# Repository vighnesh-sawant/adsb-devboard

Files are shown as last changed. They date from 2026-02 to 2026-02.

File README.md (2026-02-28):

# adsb-devboard
A devboard with an fpga  and an ADS-B reciever

# Why
When I was younger, I always wanted to tinker with radio stuff. When I learned airplanes broadcast  
all of their info on rf just like that, I tried naievly to process that using my phone thinking it had a rf reciever so it probably can.  
As it turns out it can't/ or is locked down so it can't.
So on learning about blueprint, I made by childhood dream come true!

# How
Get the pcb and a antenna(should be able to do for 1090Mhz),wire it to the correct gpio ports(more info soon)  
keep it in an open area, then flashing my firmware (not complete yet) should get you data about a good amount of flights in the vicinity    
(according to my research 50km ish)(more details once i try this out, I have done research but yk Murphy's law once I try out I'll have solid instructions!)

# Pics




# Bom
| JLCPCB BOM Tool - BOM Matching | | | | | | | | | | | | | | | | | |
| --- | --- | --- | --- | --- | --- | --- | --- | --- | --- | --- | --- | --- | --- | --- | --- | --- | --- |
| BOM name：rev3_bom-JLCPCB Assembly Order.xlsx | | | Download Time：2026-03-01 03:22:45 | | | | * Our matching results are updated in real-time, but stock and prices may change. 
If it's been over 24 hours, please re-match before placing your order. |                 |                                                                                                                                                                                   |                                              |                                                                                                                                                                                                                              |                   |                                                                          |          |     |           |                 |
| PCB Assembled Qty：5                                                                 |                   |                             | Est. Total Price：59.8411                 |               |                    |                        |                                                                                                                                                           |                 |                                                                                                                                                                                   |                                              |                                                                                                                                                                                                                              |                   |                                                                          |          |     |           |                 |
| Your BOM                                                                            |                   |                             |                                          |               | Matched Parts      |                        |                                                                                                                                                           |                 |                                                                                                                                                                                   |                                              |                                                                                                                                                                                                                              | Order Information |                                                                          |          |     |           |                 |
| Top Designator                                                                      | Bottom Designator | Comment                     | Footprint                                | JLCPCB Part # | Matches            | Part #                 | Manufacturer                                                                                                                                              | Footprint       | Description                                                                                                                                                                       | Category                                     | Warning                                                                                                                                                                                                                      | JLCPCB Part #     | Product link                                                             | Lib Type | Qty | Source    | Total Price ($) |
| C1,C2                                                                               |                   | 33p                         | 0402                                     |               | Unconfirmed        | 0402CG330J500NT        | FH (Guangdong Fenghua Advanced Tech)                                                                                                                      | 0402            | 33pF 50V C0G ±5% 0402 Multilayer Ceramic Capacitors MLCC - SMD/SMT ROHS                                                                                                           | Multilayer Ceramic Capacitors MLCC - SMD/SMT | 1.The comment (0402CG330J500NT) of this part does not match the one (33p) provided in your BOM. Please confirm;                                                                                                              | C1562             | https://jlcpcb.com/partdetail/1914-0402CG330J500NT/C1562                 | Basic    | 4   | 4 JLCPCB  | 0.0048          |
| C10,C11,C12,C13,C14,C15,C17,C18,C19,C21,C33,C35,C37,C41,C43,C45,C47,C48,C6,C7,C8,C9 |                   | 100n                        | 0402                                     |               | Unconfirmed        | CL05B104KO5NNNC        | Samsung Electro-Mechanics                                                                                                                                 | 0402            | 100nF 16V X7R ±10% 0402 Multilayer Ceramic Capacitors MLCC - SMD/SMT ROHS                                                                                                         | Multilayer Ceramic Capacitors MLCC - SMD/SMT | 1.The comment (CL05B104KO5NNNC) of this part does not match the one (100n) provided in your BOM. Please confirm;                                                                                                             | C1525             | https://jlcpcb.com/partdetail/1877-CL05B104KO5NNNC/C1525                 | Basic    | 44  | 44 JLCPCB | 0.0572          |
| C16,C23,C3,C32,C34,C36,C38,C4,C40,C42,C44,C5                                        |                   | 4.7u                        | 0402                                     |               | Unconfirmed        | CL05A475MP5NRNC        | Samsung Electro-Mechanics                                                                                                                                 | 0402            | 10V 4.7uF X5R ±20% 0402 Multilayer Ceramic Capacitors MLCC - SMD/SMT ROHS                                                                                                         | Multilayer Ceramic Capacitors MLCC - SMD/SMT | 1.The comment (CL05A475MP5NRNC) of this part does not match the one (4.7u) provided in your BOM. Please confirm;                                                                                                             | C23733            | https://jlcpcb.com/partdetail/24469-CL05A475MP5NRNC/C23733               | Basic    | 24  | 24 JLCPCB | 0.12            |
| C20,C22                                                                             |                   | 22u                         | 0603                                     |               | Unconfirmed        | CL10A226MQ8NRNC        | Samsung Electro-Mechanics                                                                                                                                 | 0603            | 22uF 6.3V X5R ±20% 0603 Multilayer Ceramic Capacitors MLCC - SMD/SMT ROHS                                                                                                         | Multilayer Ceramic Capacitors MLCC - SMD/SMT | 1.The comment (CL10A226MQ8NRNC) of this part does not match the one (22u) provided in your BOM. Please confirm;                                                                                                              | C59461            | https://jlcpcb.com/partdetail/60514-CL10A226MQ8NRNC/C59461               | Basic    | 4   | 4 JLCPCB  | 0.038           |
| C24,C25                                                                             |                   | 10u                         | 0603                                     |               | Unconfirmed        | CL10A106KP8NNNC        | Samsung Electro-Mechanics                                                                                                                                 | 0603            | 10V 10uF X5R ±10% 0603 Multilayer Ceramic Capacitors MLCC - SMD/SMT ROHS                                                                                                          | Multilayer Ceramic Capacitors MLCC - SMD/SMT | 1.The comment (CL10A106KP8NNNC) of this part does not match the one (10u) provided in your BOM. Please confirm;                                                                                                              | C19702            | https://jlcpcb.com/partdetail/20411-CL10A106KP8NNNC/C19702               | Basic    | 4   | 4 JLCPCB  | 0.0264          |
| C26,C28                                                                             |                   | 680p                        | 0603                                     |               | Unconfirmed        | 0603B681K500NT         | FH (Guangdong Fenghua Advanced Tech)                                                                                                                      | 0603            | 50V 680pF X7R ±10% 0603 Multilayer Ceramic Capacitors MLCC - SMD/SMT ROHS                                                                                                         | Multilayer Ceramic Capacitors MLCC - SMD/SMT | 1.The comment (0603B681K500NT) of this part does not match the one (680p) provided in your BOM. Please confirm;                                                                                                              | C1630             | https://jlcpcb.com/partdetail/1982-0603B681K500NT/C1630                  | Extended | 20  | 20 JLCPCB | 0.064           |
| C29,C30                                                                             |                   | 100n                        | 0603                                     |               | Unconfirmed        | CC0603KRX7R9BB104      | YAGEO                                                                                                                                                     | 0603            | 100nF 50V X7R ±10% 0603 Multilayer Ceramic Capacitors MLCC - SMD/SMT ROHS                                                                                                         | Multilayer Ceramic Capacitors MLCC - SMD/SMT | 1.The comment (CC0603KRX7R9BB104) of this part does not match the one (100n) provided in your BOM. Please confirm;                                                                                                           | C14663            | https://jlcpcb.com/partdetail/YAGEO-CC0603KRX7R9BB104/C14663             | Basic    | 4   | 4 JLCPCB  | 0.01            |
| C31                                                                                 |                   | 1000p                       | 0402                                     |               | Unconfirmed        | 0402B102K500NT         | FH (Guangdong Fenghua Advanced Tech)                                                                                                                      | 0402            | 1nF 50V X7R ±10% 0402 Multilayer Ceramic Capacitors MLCC - SMD/SMT ROHS                                                                                                           | Multilayer Ceramic Capacitors MLCC - SMD/SMT | 1.The comment (0402B102K500NT) of this part does not match the one (1000p) provided in your BOM. Please confirm;                                                                                                             | C1523             | https://jlcpcb.com/partdetail/1875-0402B102K500NT/C1523                  | Basic    | 2   | 2 JLCPCB  | 0.0024          |
| C39                                                                                 |                   | 10u                         | 0402                                     |               | Unconfirmed        | CL05A106MQ5NUNC        | Samsung Electro-Mechanics                                                                                                                                 | 0402            | 10uF 6.3V X5R ±20% 0402 Multilayer Ceramic Capacitors MLCC - SMD/SMT ROHS                                                                                                         | Multilayer Ceramic Capacitors MLCC - SMD/SMT | 1.The comment (CL05A106MQ5NUNC) of this part does not match the one (10u) provided in your BOM. Please confirm;                                                                                                              | C15525            | https://jlcpcb.com/partdetail/16204-CL05A106MQ5NUNC/C15525               | Basic    | 2   | 2 JLCPCB  | 0.0112          |
| C46                                                                                 |                   | 1500p                       | 0603                                     |               | Select by Customer | 0603B152K500NT         | FH (Guangdong Fenghua Advanced Tech)                                                                                                                      | 0603            | 1.5nF 50V X7R ±10% 0603 Multilayer Ceramic Capacitors MLCC - SMD/SMT ROHS                                                                                                         | Multilayer Ceramic Capacitors MLCC - SMD/SMT | 1.The comment (0603B152K500NT) of this part does not match the one (1500p) provided in your BOM. Please confirm;
2.Multiple lines in the BOM have been matched to the same part. Please check if the matching is correct. ;  | C1595             | https://jlcpcb.com/partdetail/1947-0603B152K500NT/C1595                  | Extended | 20  | 20 JLCPCB | 0.058           |
| C52                                                                                 |                   | 1500pf                      | 0603                                     |               | Select by Customer | 0603B152K500NT         | FH (Guangdong Fenghua Advanced Tech)                                                                                                                      | 0603            | 1.5nF 50V X7R ±10% 0603 Multilayer Ceramic Capacitors MLCC - SMD/SMT ROHS                                                                                                         | Multilayer Ceramic Capacitors MLCC - SMD/SMT | 1.The comment (0603B152K500NT) of this part does not match the one (1500pf) provided in your BOM. Please confirm;
2.Multiple lines in the BOM have been matched to the same part. Please check if the matching is correct. ; | C1595             | https://jlcpcb.com/partdetail/1947-0603B152K500NT/C1595                  | Extended | 20  | 20 JLCPCB | 0.058           |
| C49                                                                                 |                   | 2.2u                        | 0603                                     |               | Unconfirmed        | CL10A225KO8NNNC        | Samsung Electro-Mechanics                                                                                                                                 | 0603            | 16V 2.2uF X5R ±10% 0603 Multilayer Ceramic Capacitors MLCC - SMD/SMT ROHS                                                                                                         | Multilayer Ceramic Capacitors MLCC - SMD/SMT | 1.The comment (CL10A225KO8NNNC) of this part does not match the one (2.2u) provided in your BOM. Please confirm;                                                                                                             | C23630            | https://jlcpcb.com/partdetail/24366-CL10A225KO8NNNC/C23630               | Basic    | 2   | 2 JLCPCB  | 0.0124          |
| C50                                                                                 |                   | 1000p                       | 0603                                     |               | Unconfirmed        | CL10B102KB8NNNC        | Samsung Electro-Mechanics                                                                                                                                 | 0603            | 1nF 50V X7R ±10% 0603 Multilayer Ceramic Capacitors MLCC - SMD/SMT ROHS                                                                                                           | Multilayer Ceramic Capacitors MLCC - SMD/SMT | 1.The comment (CL10B102KB8NNNC) of this part does not match the one (1000p) provided in your BOM. Please confirm;                                                                                                            | C1588             | https://jlcpcb.com/partdetail/1940-CL10B102KB8NNNC/C1588                 | Basic    | 2   | 2 JLCPCB  | 0.0066          |
| C53                                                                                 |                   | 3p                          | 0603                                     |               | Unconfirmed        | 0603CG3R0C500NT        | FH (Guangdong Fenghua Advanced Tech)                                                                                                                      | 0603            | 3pF 50V C0G 0603 Multilayer Ceramic Capacitors MLCC - SMD/SMT ROHS                                                                                                                | Multilayer Ceramic Capacitors MLCC - SMD/SMT | 1.The comment (0603CG3R0C500NT) of this part does not match the one (3p) provided in your BOM. Please confirm;                                                                                                               | C46219            | https://jlcpcb.com/partdetail/47222-0603CG3R0C500NT/C46219               | Extended | 20  | 20 JLCPCB | 0.062           |
| C54                                                                                 |                   | 200p                        | 0603                                     |               | Unconfirmed        | 0603B201K500NT         | FH (Guangdong Fenghua Advanced Tech)                                                                                                                      | 0603            | 200pF 50V X7R ±10% 0603 Multilayer Ceramic Capacitors MLCC - SMD/SMT ROHS                                                                                                         | Multilayer Ceramic Capacitors MLCC - SMD/SMT | 1.The comment (0603B201K500NT) of this part does not match the one (200p) provided in your BOM. Please confirm;                                                                                                              | C1600             | https://jlcpcb.com/partdetail/1952-0603B201K500NT/C1600                  | Extended | 20  | 20 JLCPCB | 0.088           |
| D1,D2,D3,D4,D5,D6                                                                   |                   | LED                         | 0603                                     |               | Unconfirmed        | KT-0603W               | Hubei KENTO Elec                                                                                                                                          | 0603            | 100mW 120° 2.6V~3.1V 360mcd 5mA Discrete Diode Top-mount White Yellow Lens 0603 LED Indication - Discrete ROHS                                                                    | LED Indication - Discrete                    | 1.The comment (KT-0603W) of this part does not match the one (LED) provided in your BOM. Please confirm;                                                                                                                     | C2290             | https://jlcpcb.com/partdetail/Hubei_KENTOElec-KT0603W/C2290              | Basic    | 12  | 12 JLCPCB | 0.1416          |
| FB1,FB2,FB3                                                                         |                   | FerriteBead                 | 0603                                     |               | Select by Customer | GZ1608D601TF           | Sunlord                                                                                                                                                   | 0603            | -55℃~+125℃ 1 200mA 450mΩ 600Ω@100MHz ±25% 0603 Ferrite Beads ROHS                                                                                                                 | Ferrite Beads                                |                                                                                                                                                                                                                              | C1002             | https://jlcpcb.com/partdetail/Sunlord-GZ1608D601TF/C1002                 | Basic    | 6   | 6 JLCPCB  | 0.0792          |
| J1                                                                                  |                   | USB_C_Receptacle_USB2.0_16P | USB_C_Receptacle_XKB_U262-16XN-4BVC11    |               | Select by Customer | TYPE-C 16PIN 2MD(073)  | SHOU HAN                                                                                                                                                  | SMD             | -25℃~+85℃ 1 16P 3A 5,000 times 5V Black Female Surface Mount, Right Angle Type-C SMD USB Connectors ROHS                                                                          | USB Connectors                               |                                                                                                                                                                                                                              | C2765186          | https://jlcpcb.com/partdetail/SHOUHAN-TYPE_C_16PIN_2MD_073/C2765186      | Extended | 3   | 3 JLCPCB  | 0.1953          |
| L1,L2,L3                                                                            |                   | AOTA-B201610S3R3-101-T      | IND-SMD_L2.0-W1.6_AOTA-B201610S3R3-101-T |               | Select by System   | AOTA-B201610S3R3-101-T | Abracon LLC                                                                                                                                               | 0806            | 0806 Power Inductors ROHS                                                                                                                                                         | Power Inductors                              |                                                                                                                                                                                                                              | C42411119         | https://jlcpcb.com/partdetail/AbraconLLC-AOTA_B201610S3R3_101T/C42411119 | Extended | 6   | 6 JLCPCB  | 1.7286          |
| L4,L5                                                                               |                   | HP0603-R10H-N               | IND-SMD_L1.6-W1.0                        |               | Select by System   | HP0603-R10H-N          | Chilisin Elec                                                                                                                                             | SMD,1.6x1mm     | 1.7GHz 100nH 470mA 49@150MHz 540mΩ Wire-wound chip inductor ±3% SMD,1.6x1mm Inductors (SMD) ROHS                                                                                  | Inductors (SMD)                              |                                                                                                                                                                                                                              | C2903685          | https://jlcpcb.com/partdetail/ChilisinElec-HP0603_R10HN/C2903685         | Extended | 6   | 6 JLCPCB  | 0.5478          |
| R1,R2                                                                               |                   | 5.1k                        | 0402                                     |               | Unconfirmed        | 0402WGF5101TCE         | UNI-ROYAL(Uniroyal Elec)                                                                                                                                  | 0402            | -55℃~+155℃ 5.1kΩ 50V 62.5mW Thick Film Resistor ±1% ±100ppm/℃ 0402 Chip Resistor - Surface Mount ROHS                                                                             | Chip Resistor - Surface Mount                | 1.The comment (0402WGF5101TCE) of this part does not match the one (5.1k) provided in your BOM. Please confirm;                                                                                                              | C25905            | https://jlcpcb.com/partdetail/26648-0402WGF5101TCE/C25905                | Basic    | 4   | 4 JLCPCB  | 0.0032          |
| R3,R4                                                                               |                   | 27                          | 0402                                     |               | Unconfirmed        | 0402WGF270JTCE         | UNI-ROYAL(Uniroyal Elec)                                                                                                                                  | 0402            | -55℃~+155℃ 27Ω 50V 62.5mW Thick Film Resistor ±1% ±100ppm/℃ 0402 Chip Resistor - Surface Mount ROHS                                                                               | Chip Resistor - Surface Mount                | 1.The comment (0402WGF270JTCE) of this part does not match the one (27) provided in your BOM. Please confirm;                                                                                                                | C25100            | https://jlcpcb.com/partdetail/25843-0402WGF270JTCE/C25100                | Extended | 20  | 20 JLCPCB | 0.016           |
| R6                                                                                  |                   | 33                          | 0402                                     |               | Unconfirmed        | 0402WGF330JTCE         | UNI-ROYAL(Uniroyal Elec)                                                                                                                                  | 0402            | -55℃~+155℃ 33Ω 50V 62.5mW Thick Film Resistor ±1% ±100ppm/℃ 0402 Chip Resistor - Surface Mount ROHS                                                                               | Chip Resistor - Surface Mount                | 1.The comment (0402WGF330JTCE) of this part does not match the one (33) provided in your BOM. Please confirm;                                                                                                                | C25105            | https://jlcpcb.com/partdetail/25848-0402WGF330JTCE/C25105                | Basic    | 2   | 2 JLCPCB  | 0.0016          |
| R10,R9                                                                              |                   | 51k                         | 0402                                     |               | Unconfirmed        | 0402WGF5102TCE         | UNI-ROYAL(Uniroyal Elec)                                                                                                                                  | 0402            | -55℃~+155℃ 50V 51kΩ 62.5mW Thick Film Resistor ±1% ±100ppm/℃ 0402 Chip Resistor - Surface Mount ROHS                                                                              | Chip Resistor - Surface Mount                | 1.The comment (0402WGF5102TCE) of this part does not match the one (51k) provided in your BOM. Please confirm;                                                                                                               | C25794            | https://jlcpcb.com/partdetail/26537-0402WGF5102TCE/C25794                | Basic    | 4   | 4 JLCPCB  | 0.0036          |
| R11                                                                                 |                   | 22k                         | 0402                                     |               | Unconfirmed        | 0402WGF2202TCE         | UNI-ROYAL(Uniroyal Elec)                                                                                                                                  | 0402            | -55℃~+155℃ 22kΩ 50V 62.5mW Thick Film Resistor ±1% ±100ppm/℃ 0402 Chip Resistor - Surface Mount ROHS                                                                              | Chip Resistor - Surface Mount                | 1.The comment (0402WGF2202TCE) of this part does not match the one (22k) provided in your BOM. Please confirm;                                                                                                               | C25768            | https://jlcpcb.com/partdetail/26511-0402WGF2202TCE/C25768                | Basic    | 2   | 2 JLCPCB  | 0.0016          |
| R12,R32                                                                             |                   | 100k                        | 0402                                     |               | Unconfirmed        | 0402WGF1003TCE         | UNI-ROYAL(Uniroyal Elec)                                                                                                                                  | 0402            | -55℃~+155℃ 100kΩ 50V 62.5mW Thick Film Resistor ±1% ±100ppm/℃ 0402 Chip Resistor - Surface Mount ROHS                                                                             | Chip Resistor - Surface Mount                | 1.The comment (0402WGF1003TCE) of this part does not match the one (100k) provided in your BOM. Please confirm;                                                                                                              | C25741            | https://jlcpcb.com/partdetail/26484-0402WGF1003TCE/C25741                | Basic    | 4   | 4 JLCPCB  | 0.0032          |
| R13                                                                                 |                   | 120                         | 0402                                     |               | Unconfirmed        | 0402WGF1200TCE         | UNI-ROYAL(Uniroyal Elec)                                                                                                                                  | 0402            | -55℃~+155℃ 120Ω 50V 62.5mW Thick Film Resistor ±1% ±100ppm/℃ 0402 Chip Resistor - Surface Mount ROHS                                                                              | Chip Resistor - Surface Mount                | 1.The comment (0402WGF1200TCE) of this part does not match the one (120) provided in your BOM. Please confirm;                                                                                                               | C25079            | https://jlcpcb.com/partdetail/25822-0402WGF1200TCE/C25079                | Basic    | 2   | 2 JLCPCB  | 0.0014          |
| R14,R15,R16,R17,R18,R19,R20,R21,R24,R27,R28                                         |                   | 100                         | 0402                                     |               | Unconfirmed        | 0402WGF1000TCE         | UNI-ROYAL(Uniroyal Elec)                                                                                                                                  | 0402            | -55℃~+155℃ 100Ω 50V 62.5mW Thick Film Resistor ±1% ±100ppm/℃ 0402 Chip Resistor - Surface Mount ROHS                                                                              | Chip Resistor - Surface Mount                | 1.The comment (0402WGF1000TCE) of this part does not match the one (100) provided in your BOM. Please confirm;                                                                                                               | C25076            | https://jlcpcb.com/partdetail/25819-0402WGF1000TCE/C25076                | Basic    | 22  | 22 JLCPCB | 0.0154          |
| R22,R30,R5,R7                                                                       |                   | 1K                          | 0402                                     |               | Unconfirmed        | 0402WGF1001TCE         | UNI-ROYAL(Uniroyal Elec)                                                                                                                                  | 0402            | -55℃~+155℃ 1kΩ 50V 62.5mW Thick Film Resistor ±1% ±100ppm/℃ 0402 Chip Resistor - Surface Mount ROHS                                                                               | Chip Resistor - Surface Mount                | 1.The comment (0402WGF1001TCE) of this part does not match the one (1K) provided in your BOM. Please confirm;                                                                                                                | C11702            | https://jlcpcb.com/partdetail/12256-0402WGF1001TCE/C11702                | Basic    | 8   | 8 JLCPCB  | 0.0056          |
| R25,R31,R8                                                                          |                   | 10K                         | 0402                                     |               | Unconfirmed        | 0402WGF1002TCE         | UNI-ROYAL(Uniroyal Elec)                                                                                                                                  | 0402            | -55℃~+155℃ 10kΩ 50V 62.5mW Thick Film Resistor ±1% ±100ppm/℃ 0402 Chip Resistor - Surface Mount ROHS                                                                              | Chip Resistor - Surface Mount                | 1.The comment (0402WGF1002TCE) of this part does not match the one (10K) provided in your BOM. Please confirm;                                                                                                               | C25744            | https://jlcpcb.com/partdetail/26487-0402WGF1002TCE/C25744                | Basic    | 6   | 6 JLCPCB  | 0.0048          |
| R26                                                                                 |                   | 2.2K                        | 0402                                     |               | Unconfirmed        | 0402WGF2201TCE         | UNI-ROYAL(Uniroyal Elec)                                                                                                                                  | 0402            | -55℃~+155℃ 2.2kΩ 50V 62.5mW Thick Film Resistor ±1% ±100ppm/℃ 0402 Chip Resistor - Surface Mount ROHS                                                                             | Chip Resistor - Surface Mount                | 1.The comment (0402WGF2201TCE) of this part does not match the one (2.2K) provided in your BOM. Please confirm;                                                                                                              | C25879            | https://jlcpcb.com/partdetail/26622-0402WGF2201TCE/C25879                | Basic    | 2   | 2 JLCPCB  | 0.0016          |
| R29                                                                                 |                   | 53.6                        | 0402                                     |               | Unconfirmed        | 0402WGF536JTCE         | UNI-ROYAL(Uniroyal Elec)                                                                                                                                  | 0402            | -55℃~+155℃ 50V 53.6Ω 62.5mW Thick Film Resistor ±1% ±100ppm/℃ 0402 Chip Resistor - Surface Mount ROHS                                                                             | Chip Resistor - Surface Mount                | 1.The comment (0402WGF536JTCE) of this part does not match the one (53.6) provided in your BOM. Please confirm;                                                                                                              | C423156           | https://jlcpcb.com/partdetail/416106-0402WGF536JTCE/C423156              | Extended | 20  | 20 JLCPCB | 0.014           |
| SW1                                                                                 |                   | SW_Push                     | SW-SMD_L3.9-W3.0-P4.45                   |               | Select by Customer | TS-1088-AR02016        | XUNPU                                                                                                                                                     | SMD,4x3mm       | -30℃~+80℃ 1.6N 100,000 cycles 12V 2mm 3mm 4mm 50mA Black Round Button SMD(SMT) Tab SPST Surface Mount,Vertical Without Bracket SMD,4x3mm Tactile Switches ROHS                    | Tactile Switches                             |                                                                                                                                                                                                                              | C720477           | https://jlcpcb.com/partdetail/XUNPU-TS_1088AR02016/C720477               | Basic    | 2   | 2 JLCPCB  | 0.096           |
| U1                                                                                  |                   | ICE40UP5K-SG48ITR           | QFN-48-1EP_7x7mm_P0.5mm_EP5.6x5.6mm      |               | Select by Customer | ICE40UP5K-SG48I        | Lattice                                                                                                                                                   | QFN-48-EP(7x7)  | -40℃~+100℃ 1171456bit 5280 660 QFN-48-EP(7x7) Programmable Logic Device (CPLDs/FPGAs) ROHS                                                                                        | Programmable Logic Device (CPLDs/FPGAs)      |                                                                                                                                                                                                                              | C2678152          | https://jlcpcb.com/partdetail/Lattice-ICE40UP5KSG48I/C2678152            | Extended | 2   | 2 JLCPCB  | 13.5164         |
| U2                                                                                  |                   | RP2350A-QFN60               | RP2350A_QFN-60_EP_7.75x7.75_Pitch0.4mm   |               | Select by Customer | RP2350A                | Raspberry Pi                                                                                                                                              | QFN-60-EP(7x7)  | QFN-60-EP(7x7) Microcontrollers (MCU/MPU/SOC) ROHS                                                                                                                                | Microcontrollers (MCU/MPU/SOC)               |                                                                                                                                                                                                                              | C42411118         | https://jlcpcb.com/partdetail/RaspberryPi-RP2350A/C42411118              | Extended | 2   | 2 JLCPCB  | 2.4926          |
| U3                                                                                  |                   | W25Q128JVP                  | WSON-8-1EP_6x5mm_P1.27mm_EP3.4x4.3mm     |               | Unconfirmed        | W25Q128JVPIQ           | Winbond Elec                                                                                                                                              | WSON-8-EP(5x6)  | -40℃~+85℃ 100,000 cycles 10uA 120ms@(32KB) 128Mbit 133MHz 2.7V~3.6V 20 Years SPI WSON-8-EP(5x6) NOR FLASH ROHS                                                                    | NOR FLASH                                    | 1.The comment (W25Q128JVPIQ) of this part does not match the one (W25Q128JVP) provided in your BOM. Please confirm;                                                                                                          | C190862           | https://jlcpcb.com/partdetail/WinbondElec-W25Q128JVPIQ/C190862           | Extended | 2   | 2 JLCPCB  | 6.179           |
| U4                                                                                  |                   | RT8075ZQW                   | WDFN-10_L3.0-W3.0-P0.50-BL-EP            |               | Select by System   | RT8075ZQW              | Richtek Tech                                                                                                                                              | WDFN-10-EP(3x3) | -40℃~+125℃ 1.25MHz 1A 2 2.5V~5.5V 600mV~5.5V 70uA Adjustable Buck Buck Built-in Yes WDFN-10-EP(3x3) DC-DC Converters ROHS                                                         | DC-DC Converters                             |                                                                                                                                                                                                                              | C250416           | https://jlcpcb.com/partdetail/RichtekTech-RT8075ZQW/C250416              | Extended | 2   | 2 JLCPCB  | 1.0634          |
| U7                                                                                  |                   | AD8313xRM                   | MSOP-8_L3.0-W3.0-P0.65-LS4.9-BL          |               | Select by Customer | AD8313ARMZ-REEL        | Analog Devices                                                                                                                                            | MSOP-8          | -40℃~+85℃ -60dBm~10dBm 100MHz~2.5GHz 13.7mA 2.7V~5.5V ±1.0dB MSOP-8 RF Detectors ROHS                                                                                             | RF Detectors                                 |                                                                                                                                                                                                                              | C652686           | https://jlcpcb.com/partdetail/AnalogDevices-AD8313ARMZREEL/C652686       | Extended | 2   | 2 JLCPCB  | 14.1658         |
| U8                                                                                  |                   | TLV3501AID                  | SOP-8_L4.9-W3.9-P1.27-LS6.0-BL           |               | Select by System   | TLV3501AID             | Texas Instruments                                                                                                                                         | SOIC-8          | -2.75V~-1.35V、1.35V~2.75V -40℃~+125℃ 1 1.5ns 1mV 2.7V~5.5V 2pA 2pA 3.2mA 4.5ns 5.5V 5uV/℃ 6mV 70dB CMOS Push-pull Rail-to-Rail Input, Rail-to-Rail Output SOIC-8 Comparators ROHS | Comparators                                  |                                                                                                                                                                                                                              | C2861858          | https://jlcpcb.com/partdetail/TexasInstruments-TLV3501AID/C2861858       | Extended | 2   | 2 JLCPCB  | 3.4094          |
| U10,U6                                                                              |                   | SPF5189Z                    | SOT-343-4_L2.0-W1.3-P1.30-LS2.1-BR       |               | Select by Customer | PSA4-5043+             | Mini-Circuits                                                                                                                                             | SOT-343         | 0.75dB 18.4dB 19.8dBm 3V、5V 50MHz~4GHz 58mA SOT-343 RF Amplifiers ROHS                                                                                                            | RF Amplifiers                                |                                                                                                                                                                                                                              | C5240848          | https://jlcpcb.com/partdetail/MiniCircuits-PSA4_5043/C5240848            | Extended | 4   | 4 JLCPCB  | 9.232           |
| X1,X2                                                                               |                   | TA0970B                     | FILTER-SMD_6P-L3.8-W3.8-P1.27-TL-3       |               | Select by Customer | TA0970A                | TST                                                                                                                                                       | SMD3838-6P      | -40℃~+85℃ 1.09GHz 2.3dB、3dB 50Ω SMD3838-6P SAW Filters ROHS                                                                                                                       | SAW Filters                                  |                                                                                                                                                                                                                              | C7115531          | https://jlcpcb.com/partdetail/TST-TA0970A/C7115531                       | Extended | 4   | 4 JLCPCB  | 6.1568          |
| Y1                                                                                  |                   | Crystal_GND24               | Crystal_SMD_3225-4Pin_3.2x2.5mm          |               | Select by Customer | X322512MSB4SI          | YXC Crystal Oscillators                                                                                                                                   | SMD3225-4P      | -40℃~+85℃ 12MHz 20pF Crystal Oscillator ±10ppm ±20ppm SMD3225-4P Crystals ROHS                                                                                                    | Crystals                                     |                                                                                                                                                                                                                              | C9002             | https://jlcpcb.com/partdetail/YXC_CrystalOscillators-X322512MSB4SI/C9002 | Basic    | 2   | 2 JLCPCB  | 0.1462          |
| J4                                                                                  |                   | Conn_Coaxial                | SMA_BAT_Wireless_BWSMA-KWE-Z001          |               | No matches         | No Part Selected       |                                                                                                                                                           |                 |                                                                                                                                                                                   |                                              |                                                                                                                                                                                                                              |                   |                                                                          |          |     |           |                 |
| Index | LCSC#   | MPN            | Manufacturer | Package      | Customer # | Description                                                      | RoHS | Quantity | MOQ | Multiple | Unit Price($) | Extended Price($) | Product Link                                     |
| ------ | ------- | -------------- | ------------ | ------------ | ---------- | ---------------------------------------------------------------- | ---- | -------- | --- | -------- | ------------- | ----------------- | ------------------------------------------------ |
| 1      | C496551 | BWSMA-KWE-Z001 | BAT WIRELESS | Through Hole |            | Connector Receptacle SMA Female Pin 50Ω Through Hole Right Angle | yes  | 2        | 1   | 1        | 0.4986        | 1.00              | https://www.lcsc.com/product-detail/C496551.html |
| 2      | C411380 | TX4G-JKS-20    | EBYTE        | -            |            | 4G Antenna 5dBi 2.205GHz RF Antennas RoHS                        | yes  | 2        | 1   | 1        | 1.9593        | 3.92              | https://www.lcsc.com/product-detail/C411380.html |

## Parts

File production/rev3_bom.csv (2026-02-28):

Designator | Footprint | Quantity | Value | LCSC Part #
C1, C2 | 0402 | 2 | 33p
C10, C11, C12, C13, C14, C15, C17, C18, C19, C21, C33, C35, C37, C41, C43, C45, C47, C48, C6, C7, C8, C9 | 0402 | 22 | 100n
C16, C23, C3, C32, C34, C36, C38, C4, C40, C42, C44, C5 | 0402 | 12 | 4.7u
C20, C22 | 0603 | 2 | 22u
C24, C25 | 0603 | 2 | 10u
C26, C28 | 0603 | 2 | 680p
C29, C30 | 0603 | 2 | 100n
C31 | 0402 | 1 | 1000p
C39 | 0402 | 1 | 10u
C46 | 0603 | 1 | 1500p
C49 | 0603 | 1 | 2.2u
C50 | 0603 | 1 | 1000p
C52 | 0603 | 1 | 1500pf
C53 | 0603 | 1 | 3p
C54 | 0603 | 1 | 200p
D1, D2, D3, D4, D5, D6 | 0603 | 6 | LED
FB1, FB2, FB3 | 0603 | 3 | FerriteBead
J1 | USB_C_Receptacle_XKB_U262-16XN-4BVC11 | 1 | USB_C_Receptacle_USB2.0_16P
J2, J3 | PinHeader_1x20_P2.54mm_Vertical | 2 | Conn_01x20_Pin
J4 | SMA_BAT_Wireless_BWSMA-KWE-Z001 | 1 | Conn_Coaxial
L1, L2, L3 | IND-SMD_L2.0-W1.6_AOTA-B201610S3R3-101-T | 3 | AOTA-B201610S3R3-101-T | C42411119
L4, L5 | IND-SMD_L1.6-W1.0 | 2 | HP0603-R10H-N | C2903685
R1, R2 | 0402 | 2 | 5.1k
R10, R9 | 0402 | 2 | 51k
R11 | 0402 | 1 | 22k
R12, R32 | 0402 | 2 | 100k
R13 | 0402 | 1 | 120
R14, R15, R16, R17, R18, R19, R20, R21, R24, R27, R28 | 0402 | 11 | 100
R22, R30, R5, R7 | 0402 | 4 | 1K
R25, R31, R8 | 0402 | 3 | 10K
R26 | 0402 | 1 | 2.2K
R29 | 0402 | 1 | 53.6
R3, R4 | 0402 | 2 | 27
R6 | 0402 | 1 | 33
SW1 | SW-SMD_L3.9-W3.0-P4.45 | 1 | SW_Push
TP1, TP2, TP3, TP4, TP7 | TestPoint_Pad_D1.0mm | 5 | TestPoint_Alt
U1 | QFN-48-1EP_7x7mm_P0.5mm_EP5.6x5.6mm | 1 | ICE40UP5K-SG48ITR
U10, U6 | SOT-343-4_L2.0-W1.3-P1.30-LS2.1-BR | 2 | SPF5189Z
U2 | RP2350A_QFN-60_EP_7.75x7.75_Pitch0.4mm | 1 | RP2350A-QFN60
U3 | WSON-8-1EP_6x5mm_P1.27mm_EP3.4x4.3mm | 1 | W25Q128JVP
U4 | WDFN-10_L3.0-W3.0-P0.50-BL-EP | 1 | RT8075ZQW | C250416
U7 | MSOP-8_L3.0-W3.0-P0.65-LS4.9-BL | 1 | AD8313xRM
U8 | SOP-8_L4.9-W3.9-P1.27-LS6.0-BL | 1 | TLV3501AID
X1, X2 | FILTER-SMD_6P-L3.8-W3.8-P1.27-TL-3 | 2 | TA0970B
Y1 | Crystal_SMD_3225-4Pin_3.2x2.5mm | 1 | Crystal_GND24

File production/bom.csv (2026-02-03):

Designator | Footprint | Quantity | Value | LCSC Part #
C1, C2 | 0402 | 2 | 15p
C10, C11, C12, C13, C14, C15, C17, C18, C19, C21, C29, C6, C7, C8, C9 | 0402 | 15 | 100n
C16, C23, C3, C4, C5 | 0402 | 5 | 4.7u
C20, C22 | 0603 | 2 | 22u
C24, C25 | 0603 | 2 | 10u
C26, C27, C28, C31 | 0603 | 4 | 100p
C30 | 0603 | 1 | 1u
D1, D2, D3, D4, D5, D6 | 0603 | 6 | LED
FB1, FB2, FB3 | 0402 | 3 | FerriteBead
J1 | USB_C_Receptacle_XKB_U262-16XN-4BVC11 | 1 | USB_C_Receptacle_USB2.0_16P
J2, J3 | PinHeader_1x20_P2.54mm_Vertical | 2 | Conn_01x20_Pin
J4 | SMA_BAT_Wireless_BWSMA-KWE-Z001 | 1 | Conn_Coaxial
L1, L2, L3 | IND-SMD_L2.0-W1.6_AOTA-B201610S3R3-101-T | 3 | AOTA-B201610S3R3-101-T | C42411119
L4 | 0402 | 1 | 470nH
R1, R2 | 0402 | 2 | 5.1k
R10, R9 | 0402 | 2 | 51k
R11 | 0402 | 1 | 22k
R12 | 0402 | 1 | 100k
R13 | 0402 | 1 | 120
R14, R15, R16, R17, R18, R19, R20, R21 | 0402 | 8 | 100
R22 | 0402 | 1 | 330
R23 | 0402 | 1 | 51
R3, R4 | 0402 | 2 | 27
R5, R7 | 0402 | 2 | 1k
R6 | 0402 | 1 | 33
R8 | 0402 | 1 | 10k
SW1 | SW-SMD_L3.9-W3.0-P4.45 | 1 | SW_Push
TP1, TP2, TP3, TP4, TP5, TP6, TP7 | TestPoint_Pad_D1.0mm | 7 | TestPoint_Alt
U1 | QFN-48-1EP_7x7mm_P0.5mm_EP5.6x5.6mm | 1 | ICE40UP5K-SG48ITR
U2 | RP2350A_QFN-60_EP_7.75x7.75_Pitch0.4mm | 1 | RP2350A-QFN60
U3 | WSON-8-1EP_6x5mm_P1.27mm_EP3.4x4.3mm | 1 | W25Q128JVP
U4 | WDFN-10_L3.0-W3.0-P0.50-BL-EP | 1 | RT8075ZQW | C250416
U5 | LED-ARRAY-SMD_4P-L1.6-W0.8-BL-FD | 1 | TJ-S1608SW6TDSLCCYRGB-A5 | C5356078
U6 | SOT-343-4_L2.0-W1.3-P1.30-LS2.1-BR | 1 | SPF5189Z
U7 | MSOP-8_L3.0-W3.0-P0.65-LS4.9-BL | 1 | AD8313xRM
U8 | SOP-8_L4.9-W3.9-P1.27-LS6.0-BL | 1 | TLV3501AID
X1 | FILTER-SMD_6P-L3.8-W3.8-P1.27-TL-3 | 1 | TA0970B
Y1 | Crystal_SMD_3225-4Pin_3.2x2.5mm | 1 | Crystal_GND24

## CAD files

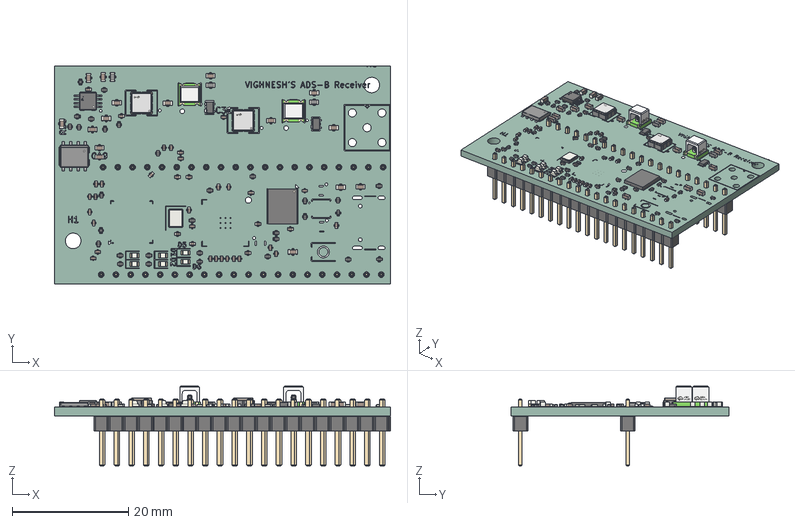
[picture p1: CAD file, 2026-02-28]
adsb-devboard.step
57.9 x 37.5 x 13.8 mm
FILTER-SMD_6P-L3.8-W3.8-P1.27-TL-3 x 2
R_0402_1005Metric x 31
C_0603_1608Metric x 16
SOP-8_L4.9-W3.9-P1.27-LS6.0-BL-1
C_0402_1005Metric x 38
WSON-8-1EP_6x5mm_P1.27mm_EP3.4x4.3mm
SMD_L3.8-W3.8_TCBT-14 x 2
SOT-343-4_L2.0-W1.3-H0.9-P1.30-LS2.1-BR x 2
Crystal_SMD_3225-4Pin_3.2x2.5mm
LED_0603_1608Metric x 6
L_0603_1608Metric x 3
MSOP-8_L3.0-W3.0-H1.1-LS4.9-P0.65
PinHeader_1x20_P2.54mm_Vertical x 2
adsb-devboard_silkscreen x 2
adsb-devboard_PCB

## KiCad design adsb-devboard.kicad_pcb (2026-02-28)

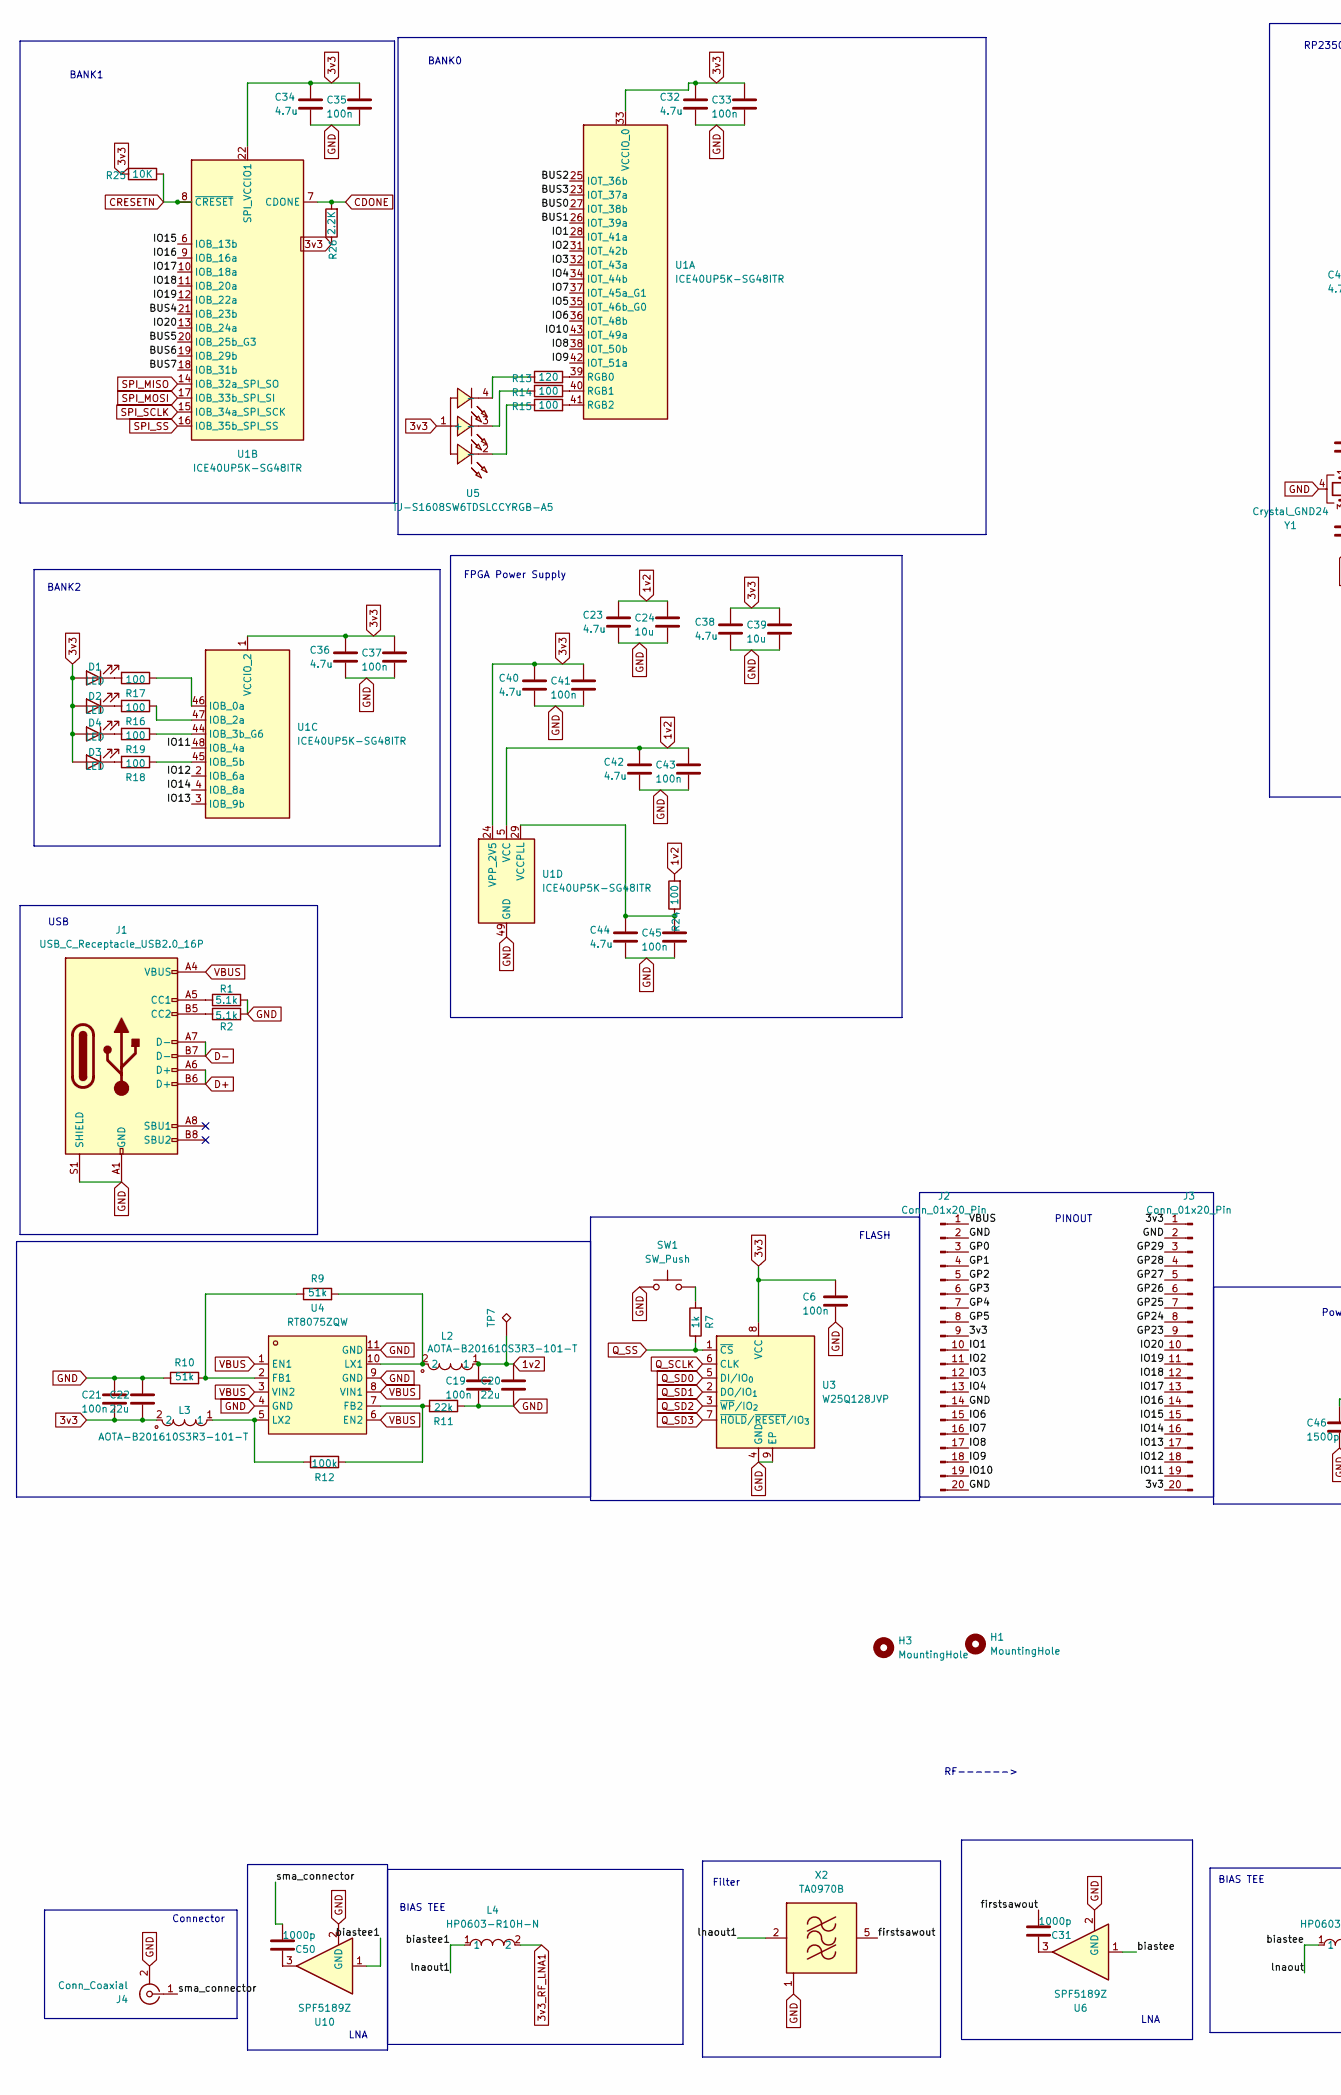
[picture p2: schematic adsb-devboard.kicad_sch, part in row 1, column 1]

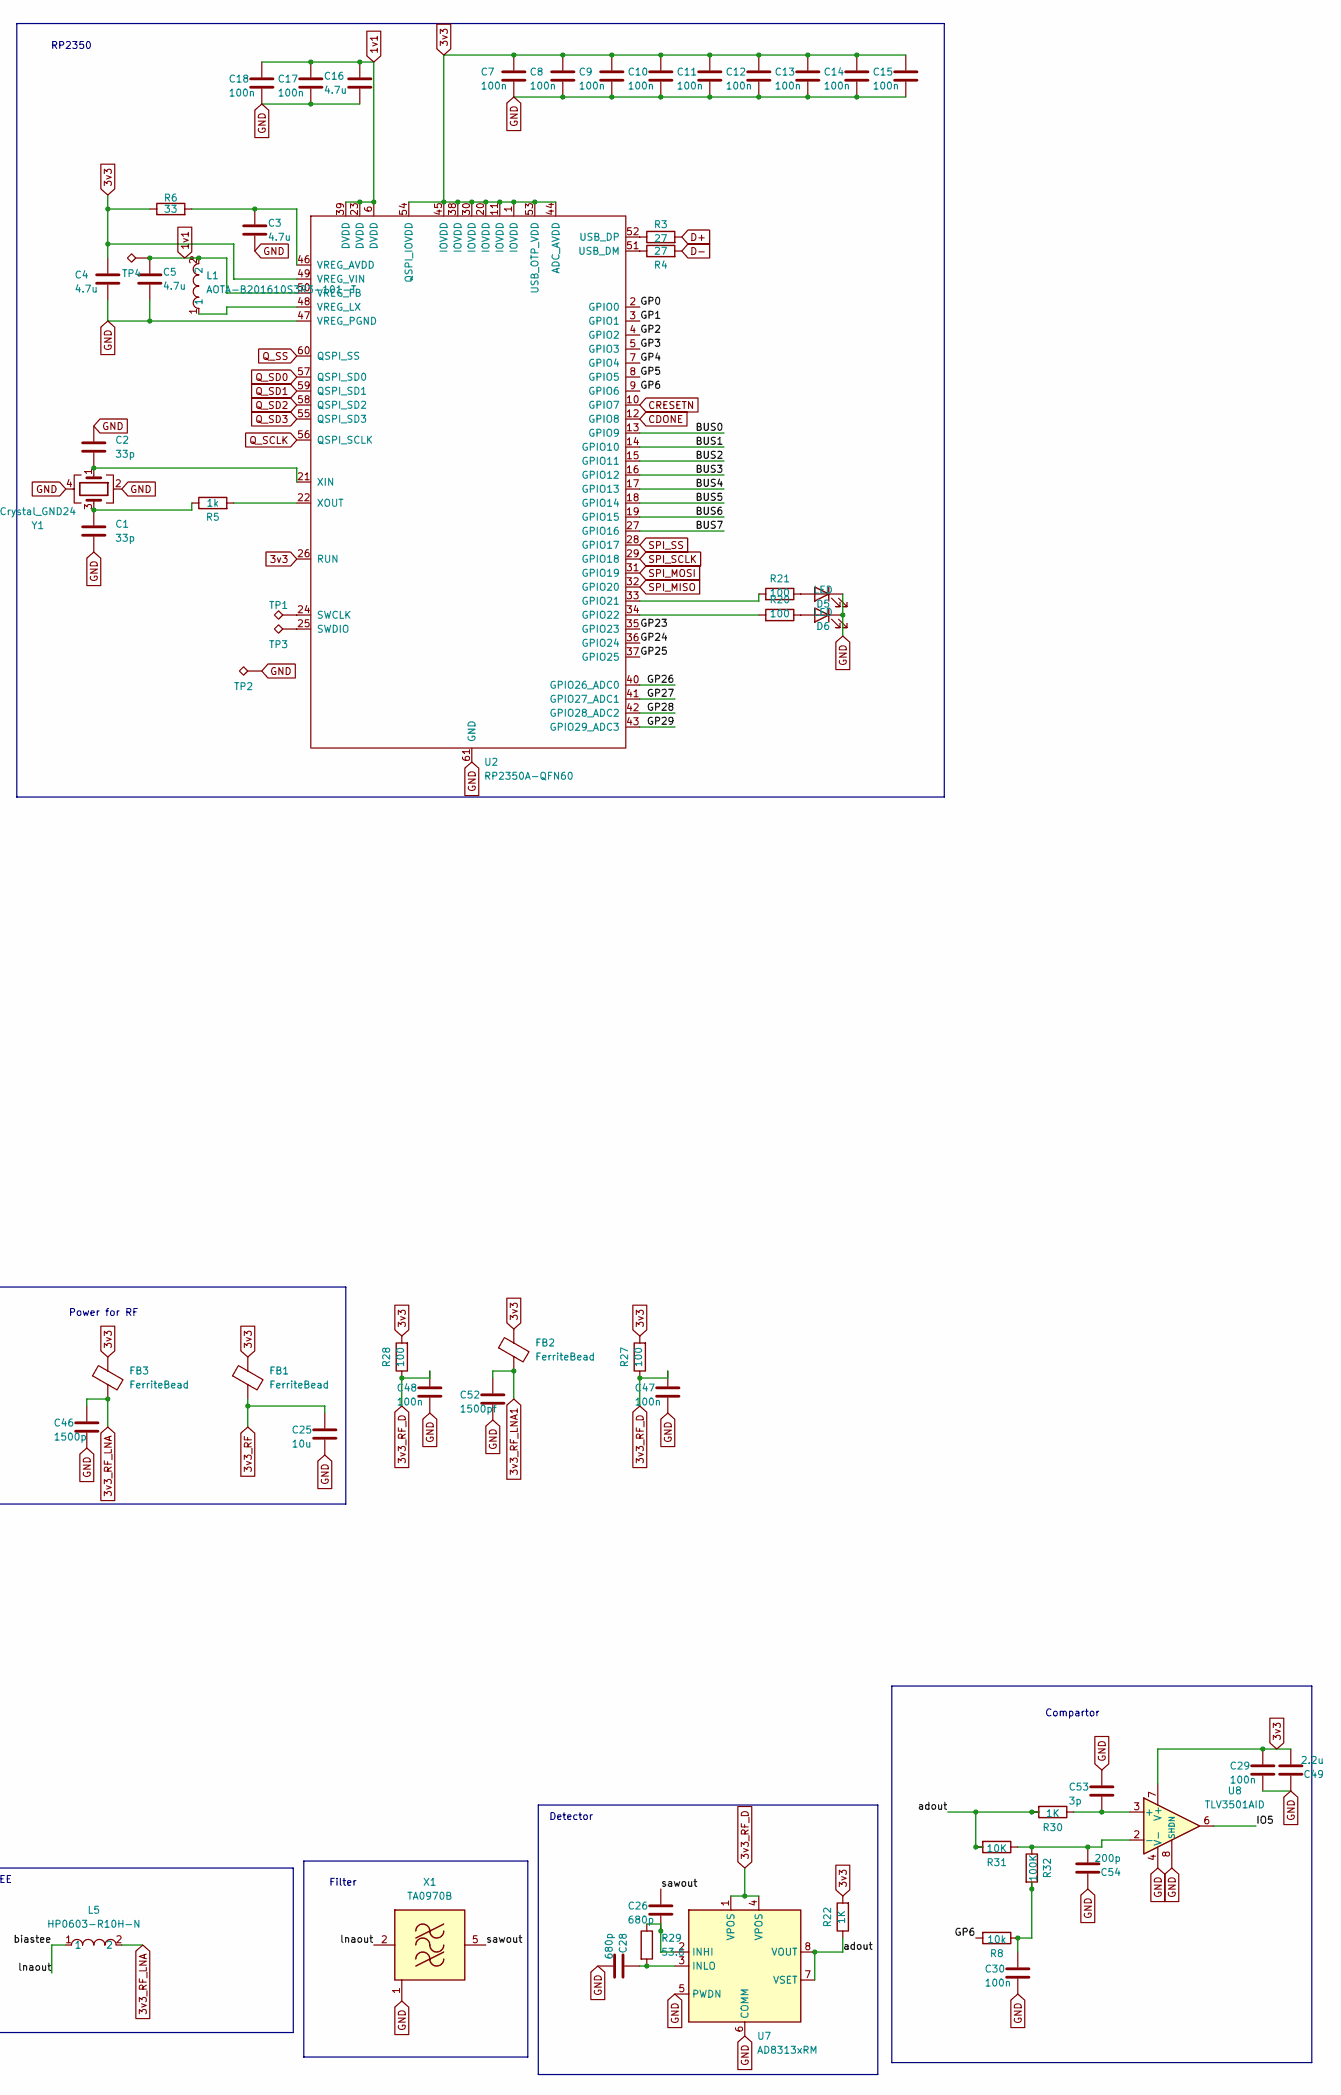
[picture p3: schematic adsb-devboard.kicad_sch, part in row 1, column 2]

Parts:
C1, C2: 33p; C_0402_1005Metric
C3, C4, C5, C16, C23, C32, C34, C36, C38, C40, C42, C44: 4.7u; C_0402_1005Metric
C6, C7, C8, C9, C10, C11, C12, C13, C14, C15, C17, C18, C19, C21, C33, C35, C37, C41, C43, C45, C47, C48: 100n; C_0402_1005Metric
C20, C22: 22u; C_0603_1608Metric
C24, C25: 10u; C_0603_1608Metric
C26, C28: 680p; C_0603_1608Metric
C29, C30: 100n; C_0603_1608Metric
C31: 1000p; C_0402_1005Metric
C39: 10u; C_0402_1005Metric
C46: 1500p; C_0603_1608Metric
C49: 2.2u; C_0603_1608Metric
C50: 1000p; C_0603_1608Metric
C52: 1500pf; C_0603_1608Metric
C53: 3p; C_0603_1608Metric
C54: 200p; C_0603_1608Metric
D1, D2, D3, D4, D5, D6: LED; LED_0603_1608Metric
FB1, FB2, FB3: FerriteBead; L_0603_1608Metric
H1, H3: MountingHole; MountingHole_2.7mm_M2.5
J1: USB_C_Receptacle_USB2.0_16P; USB_C_Receptacle_XKB_U262-16XN-4BVC11
J2, J3: Conn_01x20_Pin; PinHeader_1x20_P2.54mm_Vertical
J4: Conn_Coaxial; SMA_BAT_Wireless_BWSMA-KWE-Z001
L1, L2, L3: AOTA-B201610S3R3-101-T; IND-SMD_L2.0-W1.6_AOTA-B201610S3R3-101-T; LCSC Part C42411119
L4, L5: HP0603-R10H-N; IND-SMD_L1.6-W1.0; LCSC Part C2903685
R1, R2: 5.1k; R_0402_1005Metric
R3, R4: 27; R_0402_1005Metric
R5, R7: 1k; R_0402_1005Metric
R6: 33; R_0402_1005Metric
R8: 10k; R_0402_1005Metric
R9, R10: 51k; R_0402_1005Metric
R11: 22k; R_0402_1005Metric
R12: 100k; R_0402_1005Metric
R13: 120; R_0402_1005Metric
R14, R15, R16, R17, R18, R19, R20, R21, R24, R27, R28: 100; R_0402_1005Metric
R22, R30: 1K; R_0402_1005Metric
R25, R31: 10K; R_0402_1005Metric
R26: 2.2K; R_0402_1005Metric
R29: 53.6; R_0402_1005Metric
R32: 100K; R_0402_1005Metric
SW1: SW_Push; SW-SMD_L3.9-W3.0-P4.45
TP1, TP2, TP3, TP4, TP7: TestPoint_Alt; TestPoint_Pad_D1.0mm
U1: ICE40UP5K-SG48ITR; QFN-48-1EP_7x7mm_P0.5mm_EP5.6x5.6mm
U2: RP2350A-QFN60; RP2350A_QFN-60_EP_7.75x7.75_Pitch0.4mm
U3: W25Q128JVP; WSON-8-1EP_6x5mm_P1.27mm_EP3.4x4.3mm
U4: RT8075ZQW; WDFN-10_L3.0-W3.0-P0.50-BL-EP; LCSC Part C250416
U5: TJ-S1608SW6TDSLCCYRGB-A5; LED-ARRAY-SMD_4P-L1.6-W0.8-BL-FD; LCSC Part C5356078
U6, U10: SPF5189Z; SOT-343-4_L2.0-W1.3-P1.30-LS2.1-BR
U7: AD8313xRM; MSOP-8_L3.0-W3.0-P0.65-LS4.9-BL
U8: TLV3501AID; SOP-8_L4.9-W3.9-P1.27-LS6.0-BL
X1, X2: TA0970B; FILTER-SMD_6P-L3.8-W3.8-P1.27-TL-3
Y1: Crystal_GND24; Crystal_SMD_3225-4Pin_3.2x2.5mm

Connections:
1v1: C5.1, C16.1, C17.1, C18.1, L1.2, TP4.1, U2.6 (DVDD), U2.23 (DVDD), U2.39 (DVDD), U2.50 (VREG_FB)
1v2: C19.1, C20.1, C23.1, C24.1, C42.1, C43.1, L2.1, R24.2, TP7.1, U1.5 (VCC), U1.30 (VCC)
3v3: C4.1, C6.1, C7.1, C8.1, C9.1, C10.1, C11.1, C12.1, C13.1, C14.1, C15.1, C21.2, C22.2, C29.1, C32.1, C33.1, C34.1, C35.1, C36.1, C37.1, C38.1, C39.1, C40.1, C41.1, C49.2, D1.2 (A), D2.2 (A), D3.2 (A), D4.2 (A), FB1.1, FB2.1, FB3.1, J2.9, J3.1, J3.20, L3.2, R6.1, R22.2, R25.1, R26.1, R27.2, R28.2, U1.1 (VCCIO_2), U1.22 (SPI_VCCIO1), U1.24 (VPP_2V5), U1.33 (VCCIO_0), U2.1 (IOVDD), U2.11 (IOVDD), U2.20 (IOVDD), U2.26 (RUN), U2.30 (IOVDD), U2.38 (IOVDD), U2.44 (ADC_AVDD), U2.45 (IOVDD), U2.49 (VREG_VIN), U2.53 (USB_OTP_VDD), U2.54 (QSPI_IOVDD), U3.8 (VCC), U5.1 (+), U8.7 (V+)
3v3_RF: C25.1, FB1.2
3v3_RF_D: C47.1, C48.1, R27.1, R28.1, U7.1 (VPOS), U7.4 (VPOS)
3v3_RF_LNA: C46.1, FB3.2, L5.2
3v3_RF_LNA1: C52.1, FB2.2, L4.2
/BUS0: U1.27 (IOT_38b), U2.13 (GPIO9)
/BUS1: U1.26 (IOT_39a), U2.14 (GPIO10)
/BUS2: U1.25 (IOT_36b), U2.15 (GPIO11)
/BUS3: U1.23 (IOT_37a), U2.16 (GPIO12)
/BUS4: U1.21 (IOB_23b), U2.17 (GPIO13)
/BUS5: U1.20 (IOB_25b_G3), U2.18 (GPIO14)
/BUS6: U1.19 (IOB_29b), U2.19 (GPIO15)
/BUS7: U1.18 (IOB_31b), U2.27 (GPIO16)
/GP0: J2.3, U2.2 (GPIO0)
/GP1: J2.4, U2.3 (GPIO1)
/GP2: J2.5, U2.4 (GPIO2)
/GP3: J2.6, U2.5 (GPIO3)
/GP4: J2.7, U2.7 (GPIO4)
/GP5: J2.8, U2.8 (GPIO5)
/GP6: R8.2, U2.9 (GPIO6)
/GP23: J3.9, U2.35 (GPIO23)
/GP24: J3.8, U2.36 (GPIO24)
/GP25: J3.7, U2.37 (GPIO25)
/GP26: J3.6, U2.40 (GPIO26_ADC0)
/GP27: J3.5, U2.41 (GPIO27_ADC1)
/GP28: J3.4, U2.42 (GPIO28_ADC2)
/GP29: J3.3, U2.43 (GPIO29_ADC3)
/IO1: J2.10, U1.28 (IOT_41a)
/IO2: J2.11, U1.31 (IOT_42b)
/IO3: J2.12, U1.32 (IOT_43a)
/IO4: J2.13, U1.34 (IOT_44b)
/IO5: U1.35 (IOT_46b_G0), U8.6
/IO6: J2.15, U1.36 (IOT_48b)
/IO7: J2.16, U1.37 (IOT_45a_G1)
/IO8: J2.17, U1.38 (IOT_50b)
/IO9: J2.18, U1.42 (IOT_51a)
/IO10: J2.19, U1.43 (IOT_49a)
/IO11: J3.19, U1.48 (IOB_4a)
/IO12: J3.18, U1.2 (IOB_6a)
/IO13: J3.17, U1.3 (IOB_9b)
/IO14: J3.16, U1.4 (IOB_8a)
/IO15: J3.15, U1.6 (IOB_13b)
/IO16: J3.14, U1.9 (IOB_16a)
/IO17: J3.13, U1.10 (IOB_18a)
/IO18: J3.12, U1.11 (IOB_20a)
/IO19: J3.11, U1.12 (IOB_22a)
/IO20: J3.10, U1.13 (IOB_24a)
/adout: R22.1, R30.2, R31.2, U7.7 (VSET), U7.8 (VOUT)
/biastee: L5.1, U6.1, X1.2 (IN)
/biastee1: L4.1, U10.1, X2.2 (IN)
/firstsawout: C31.2, X2.5 (OUT)
/sawout: C26.1, X1.5 (OUT)
/sma_connector: C50.2, J4.1 (In)
CDONE: R26.2, U1.7 (CDONE), U2.12 (GPIO8)
CRESETN: R25.2, U1.8 (~CRESET), U2.10 (GPIO7)
D+: J1.A6 (D+), J1.B6 (D+), R3.2
D-: J1.A7 (D-), J1.B7 (D-), R4.2
GND: C1.2, C2.1, C3.2, C4.2, C5.2, C6.2, C7.2, C8.2, C9.2, C10.2, C11.2, C12.2, C13.2, C14.2, C15.2, C16.2, C17.2, C18.2, C19.2, C20.2, C21.1, C22.1, C23.2, C24.2, C25.2, C28.2, C29.2, C30.2, C32.2, C33.2, C34.2, C35.2, C36.2, C37.2, C38.2, C39.2, C40.2, C41.2, C42.2, C43.2, C44.2, C45.2, C46.2, C47.2, C48.2, C49.1, C52.2, C53.1, C54.1, D5.1 (K), D6.1 (K), J1.A1 (GND), J1.A12 (GND), J1.B1 (GND), J1.B12 (GND), J1.S1 (SHIELD), J2.2, J2.14, J2.20, J3.2, J4.2 (Ext), R1.2, R2.2, R10.1, R11.1, SW1.1, TP2.1, U1.49 (GND), U2.47 (VREG_PGND), U2.61 (GND), U3.4 (GND), U3.9 (EP), U4.4 (GND), U4.9 (GND), U4.11 (GND), U6.2 (GND), U7.5 (PWDN), U7.6 (COMM), U8.4 (V-), U8.8 (SHDN), U10.2 (GND), X1.1 (GND), X1.3 (GND), X1.4 (GND), X1.6 (GND), X2.1 (GND), X2.3 (GND), X2.4 (GND), X2.6 (GND), Y1.2, Y1.4
unnamed: C1.1, R5.1, Y1.3
unnamed: C30.1, R8.1, R32.2
unnamed: C31.1, U6.3
unnamed: C50.1, U10.3
unnamed: D1.1 (K), R17.2
unnamed: D2.1 (K), R16.2
unnamed: D3.1 (K), R18.2
unnamed: D4.1 (K), R19.2
unnamed: D5.2 (A), R21.1
unnamed: D6.2 (A), R20.1
unnamed: J1.A5 (CC1), R1.1
unnamed: J1.B5 (CC2), R2.1
unnamed: R7.2, SW1.2
unnamed: R13.1, U5.4 (-)
unnamed: R14.1, U5.3 (-)
unnamed: R15.1, U5.2 (-)
unnamed: R13.2, U1.39 (RGB0)
unnamed: R14.2, U1.40 (RGB1)
unnamed: R15.2, U1.41 (RGB2)
unnamed: R17.1, U1.46 (IOB_0a)
unnamed: R16.1, U1.47 (IOB_2a)
unnamed: R19.1, U1.44 (IOB_3b_G6)
unnamed: R18.1, U1.45 (IOB_5b)
unnamed: C44.1, C45.1, R24.1, U1.29 (VCCPLL)
unnamed: R21.2, U2.33 (GPIO21)
unnamed: R20.2, U2.34 (GPIO22)
unnamed: TP1.1, U2.24 (SWCLK)
unnamed: TP3.1, U2.25 (SWDIO)
unnamed: R4.1, U2.51 (USB_DM)
unnamed: R3.1, U2.52 (USB_DP)
unnamed: C3.1, R6.2, U2.46 (VREG_AVDD)
unnamed: L1.1, U2.48 (VREG_LX)
unnamed: C2.2, U2.21 (XIN), Y1.1
unnamed: R5.2, U2.22 (XOUT)
unnamed: R9.1, R10.2, U4.2 (FB1)
unnamed: R11.2, R12.1, U4.7 (FB2)
unnamed: L2.2, R9.2, U4.10 (LX1)
unnamed: L3.1, R12.2, U4.5 (LX2)
unnamed: C26.2, R29.1, U7.2 (INHI)
unnamed: C28.1, R29.2, U7.3 (INLO)
unnamed: C53.2, R30.1, U8.3 (+)
unnamed: C54.2, R31.1, R32.1, U8.2 (-)
Q_SCLK: U2.56 (QSPI_SCLK), U3.6 (CLK)
Q_SD0: U2.57 (QSPI_SD0), U3.5 (DI/IO_{0})
Q_SD1: U2.59 (QSPI_SD1), U3.2 (DO/IO_{1})
Q_SD2: U2.58 (QSPI_SD2), U3.3 (~WP/IO_{2})
Q_SD3: U2.55 (QSPI_SD3), U3.7 (~HOLD/~RESET/IO_{3})
Q_SS: R7.1, U2.60 (QSPI_SS), U3.1 (~CS)
SPI_MISO: U1.14 (IOB_32a_SPI_SO), U2.32 (GPIO20)
SPI_MOSI: U1.17 (IOB_33b_SPI_SI), U2.31 (GPIO19)
SPI_SCLK: U1.15 (IOB_34a_SPI_SCK), U2.29 (GPIO18)
SPI_SS: U1.16 (IOB_35b_SPI_SS), U2.28 (GPIO17)
VBUS: J1.A4 (VBUS), J1.A9 (VBUS), J1.B4 (VBUS), J1.B9 (VBUS), J2.1, U4.1 (EN1), U4.3 (VIN2), U4.6 (EN2), U4.8 (VIN1)

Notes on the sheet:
BIAS TEE
LNA
Filter
BANK0
Power for RF
Connector
FLASH
BANK2
RP2350
PINOUT
BANK1
RF------>
Compartor
FPGA Power Supply
USB
Detector

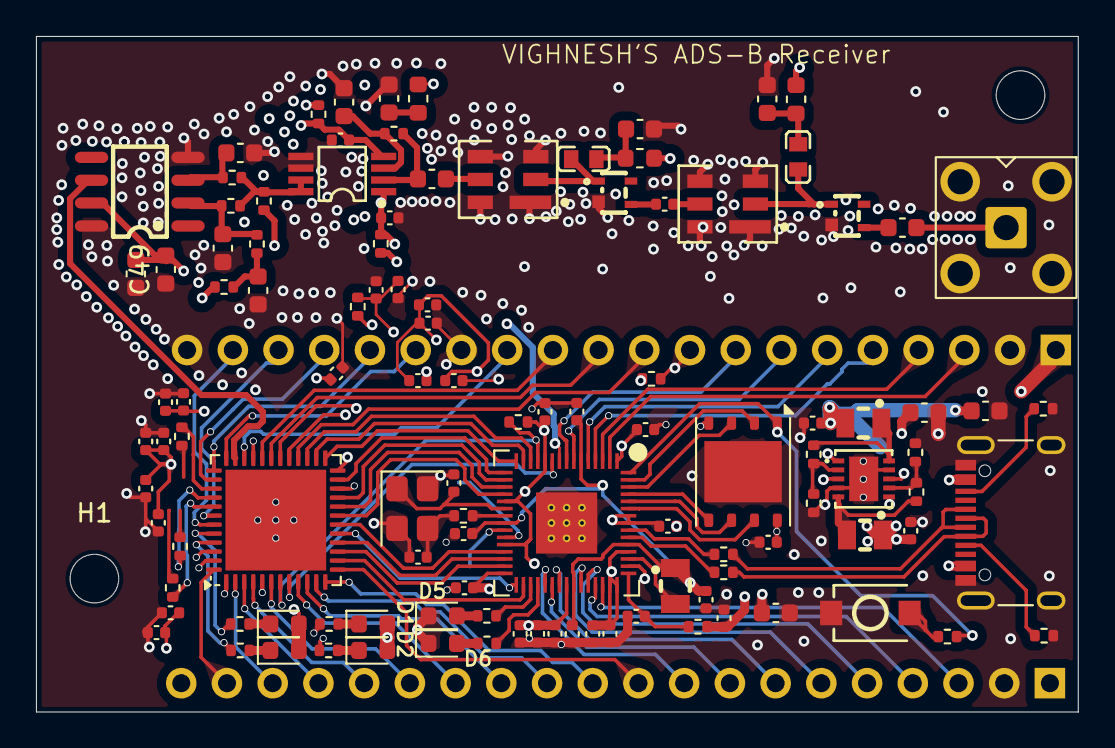
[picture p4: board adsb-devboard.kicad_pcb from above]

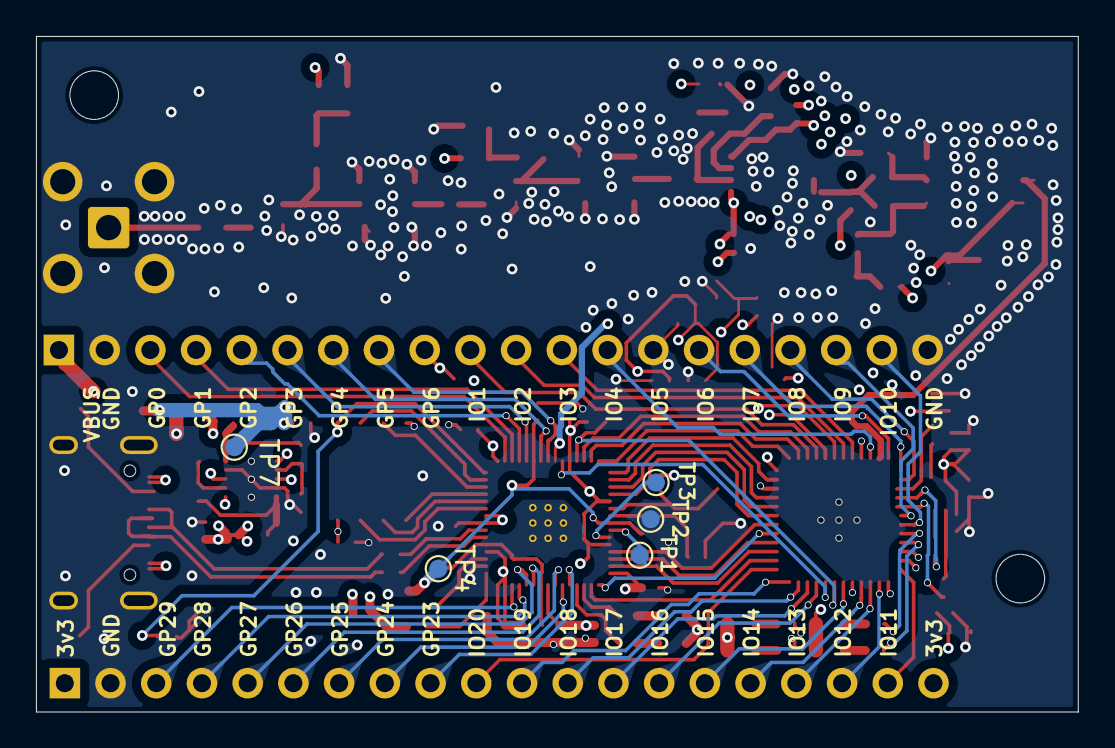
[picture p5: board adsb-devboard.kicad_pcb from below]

Board: 4 copper layers, 57.9 x 37.5 mm, 120 parts (7 on the bottom side), 110 nets.

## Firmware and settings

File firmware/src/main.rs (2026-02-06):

#![no_std]
#![no_main]

use embassy_executor::Spawner;
use embassy_rp::gpio::{Level, Output};
use embassy_rp::spi::{Config, Spi};
use embassy_time::{Duration, Timer};
use {defmt_rtt as _, panic_probe as _};

#[embassy_executor::main]
async fn main(_spawner: Spawner) {
    let p = embassy_rp::init(Default::default());

    let mut config = Config::default();
    config.frequency = 80_000_000;
}

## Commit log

2026-02-03 Add all stuff
    [adsb-devboard.kicad_pcb, adsb-devboard.kicad_sch, bom.csv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]
2026-02-03 add bom
    [bom.xls]
2026-02-06 everything seems ready
    [adsb-devboard.kicad_pcb, adsb-devboard.kicad_sch, bom.xls]
2026-02-12 add lcsc.csv
    [lcsc.csv]
2026-02-18 Revise setup instructions in README
    Updated instructions for setting up the PCB and antenna.
2026-02-24 sch cleanup and little upgrade
    [adsb-devboard.kicad_pcb, adsb-devboard.kicad_sch]
2026-02-24 rerouted rf
    [adsb-devboard.kicad_pcb]
2026-02-24 rerouted rf2
    [adsb-devboard.kicad_pcb]
2026-02-25 upddateeedd schematic
    [adsb-devboard.kicad_sch]
2026-02-28 I HAVE ROUTED THIS FOR THE NTH TIME IDK I HAVE LOST COUNT
    [adsb-devboard.kicad_pcb, adsb-devboard.kicad_sch, adsb-devboard.step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]
2026-02-28 admin stuff
    [bom.csv]
